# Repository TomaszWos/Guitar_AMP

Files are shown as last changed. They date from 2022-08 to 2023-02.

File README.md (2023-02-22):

# Guitar_AMP
Projekt wzmacniacza lampowego do domowego użytku. 
Podczas projektowania korzystałem ze schematów kultowych konstrukcji takich firm jak Marshall, Fender czy Engl.
Schematy dostępne na https://el34world.com/.

**VER_1** 

Pierwsza wersja wzmacniacza została oparta na schemacie AX84. 

Różnice występują jedynie w wartościach poszczególnych elementów.

Jest to jednokanałowy, lampowy wzmacniacz gitarowy. Układ przedwzmacniacza oparty jest na lampie ECC83 i inspirowany jest konstrukcjami Fendera.
Pozwala uzyskać klasyczne brzmienia od czystych do lekkiego chrunchu. Układ wzmacniacza mocy zbudowany został na EL84 w klasie A. Ponad to wzmacniacz posiada EQ, którego kostrukcja jest klasycznym trzystopniowe EQ jakie występowało w pierwszych wzmacniacza Fendera, Marshalla lub Voxa. 
Od nowa zostały policzone wartości napięć w układzie zasilającym oraz napięcia biasu poszczególnych katod lamp.
Układ jest podstawą do dalszych zmian i modyfikacji.

**VER_1.1**

Pierwsze modyfikacje zostały wprowadzone do układu przedwzmacniacza, tak aby rozszerzyć możliwości brzmieniowe wzmacniacza.
Została dodana druga lampa ECC83 w celu uzystania większego wzmocnienia i większej możliwości kształtowania brzmienia. Zmiana potencjometru GAIN na 1M zwiększyła wzmocnienie pierwszej triody, a co za tym idzie uzyskanie większego przesterowania.
Dodano drugi potencjometr GAIN za drugą triodą. Rozszerzono układ o drugi kanał o dużym przesterowaniu. Przełącznik SW1 służy do zmiany kanałów. Przester tworzy układ diod, które zaczynają przewodzić po osiągnięciu około napięcia 2V. Sygnał zostaje ścięty i kształtem jest zbliżony do prostokątnego. Kondensator 1n przepuszcza wysokie częstotliwości tak, aby dźwięk był mniej syczący. 
Rezystor na pierwszej katodzie zmieniono na 2.2k a kondensator na 680n. Sprawia to, że wyższe częstotliwości są bardziej wzmacniane niż niskie. Dodano kondensatory na torze sygnałowym tak, aby zwiększyć zawartość wyższych harmonicznych w sygnale. Brzmienie jest znacznie jaśniejsze i bardziej szkliste na wzór wzmacniaczy Marshall.

**VER_2**

W pełni lampowy wzmacniacz w klasie A z dwoma kanałami : Clean i Lead. Kanał Lead jest oparty na 4 triodach i jest stylizowany na wzmacniaczach typu Hi-Gain firmy ENGL.

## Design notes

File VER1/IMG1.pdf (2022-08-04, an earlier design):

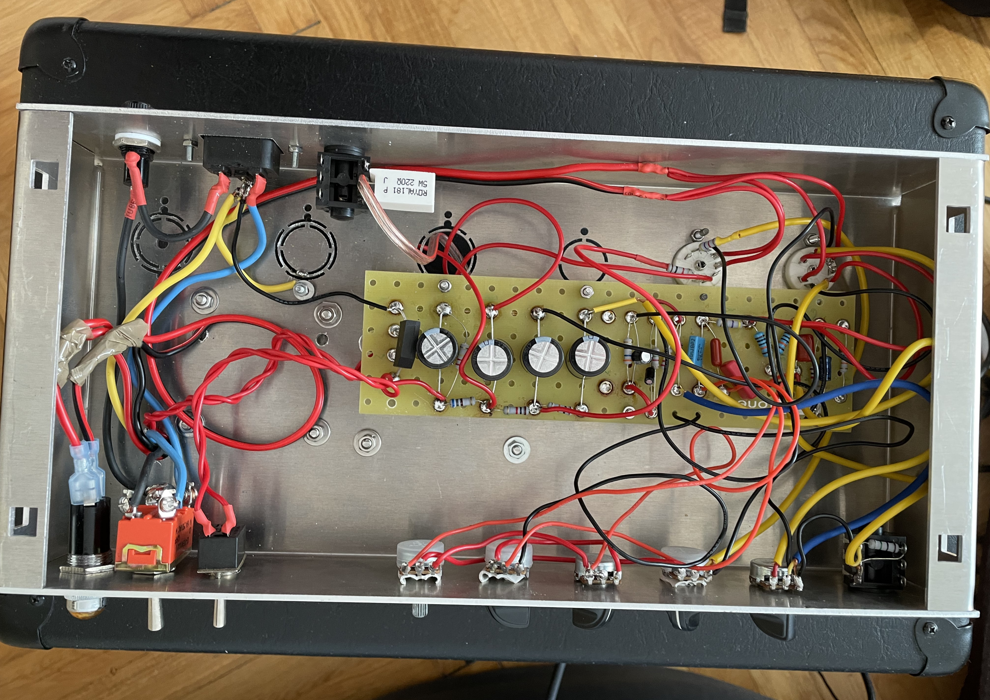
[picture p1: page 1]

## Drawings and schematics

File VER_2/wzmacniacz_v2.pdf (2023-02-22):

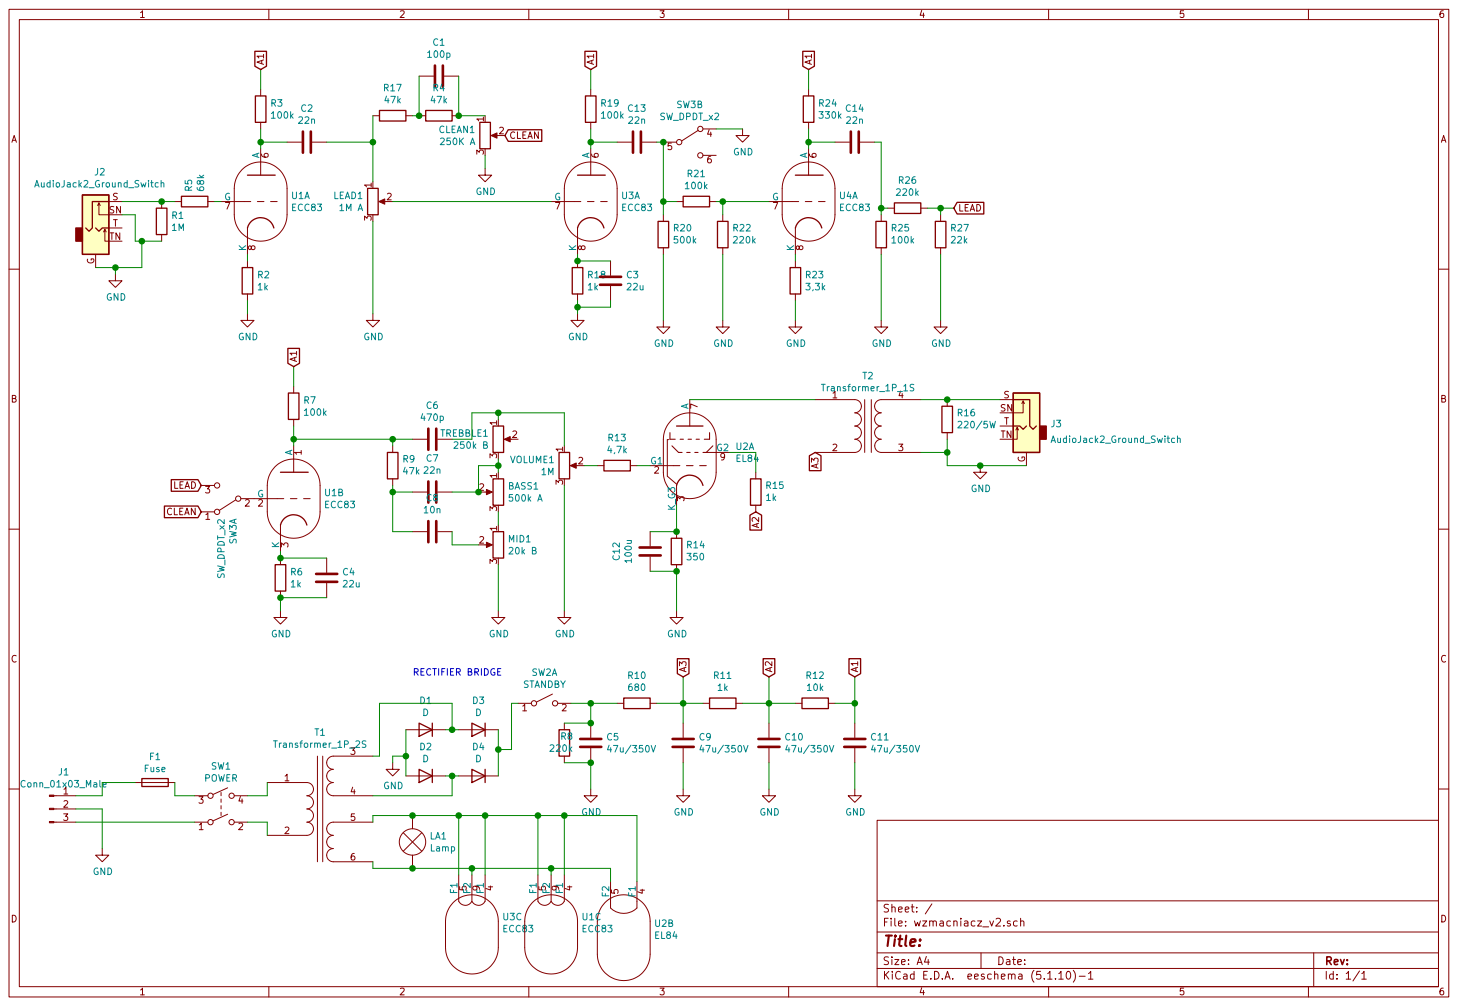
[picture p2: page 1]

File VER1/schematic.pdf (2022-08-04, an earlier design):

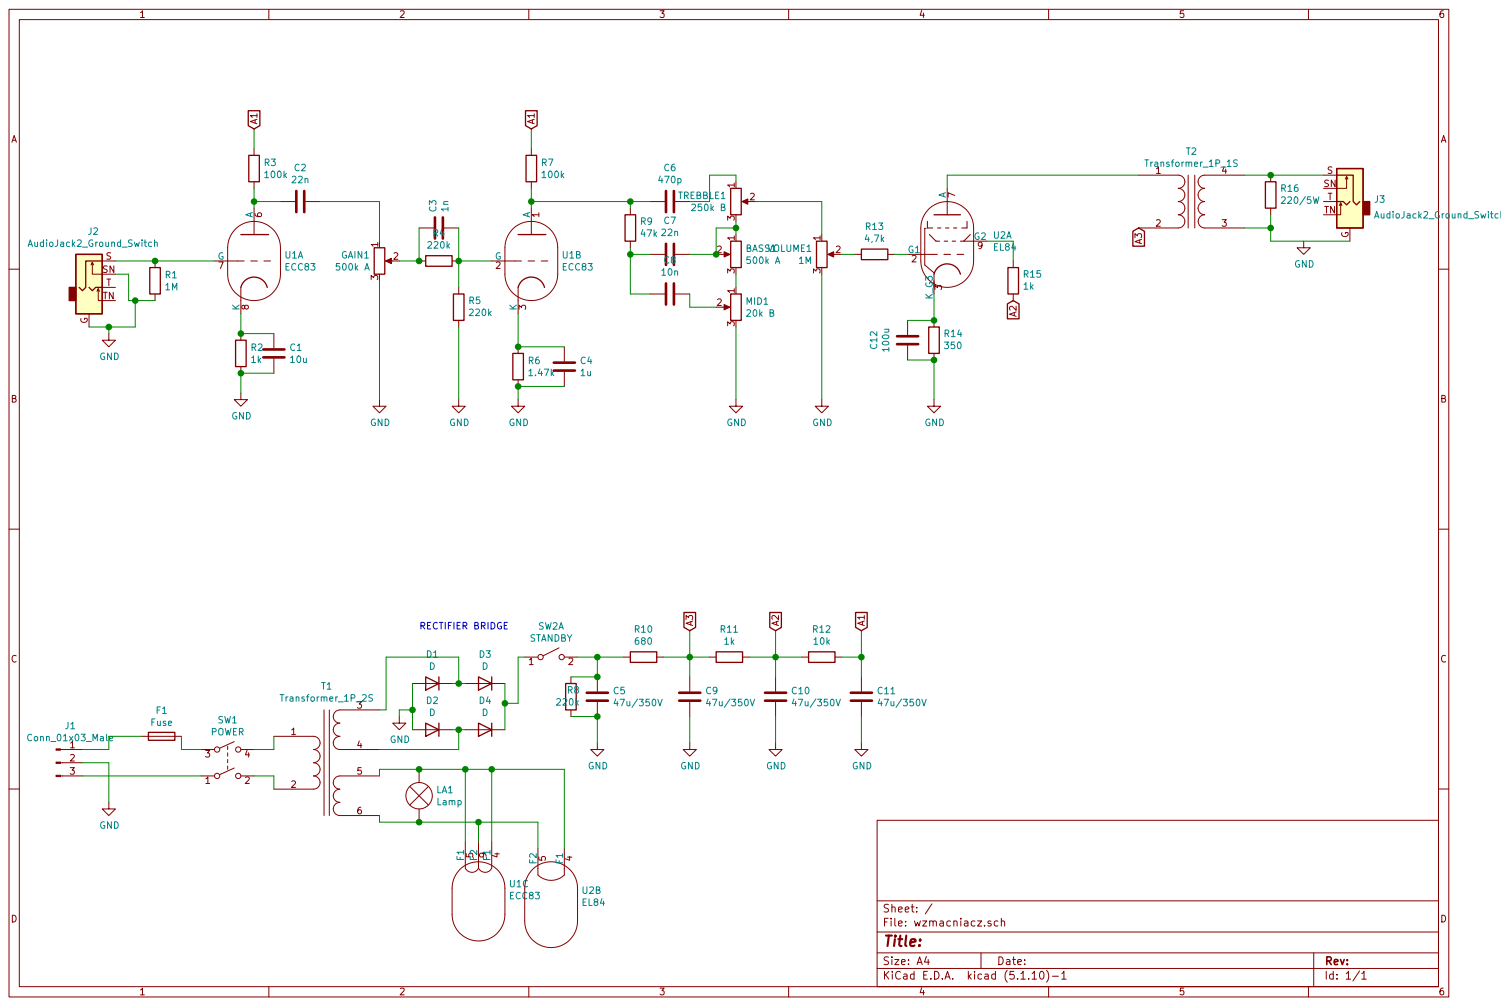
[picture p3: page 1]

Id: 1/1 Title: File: wzmacniacz.sch Sheet: / GND

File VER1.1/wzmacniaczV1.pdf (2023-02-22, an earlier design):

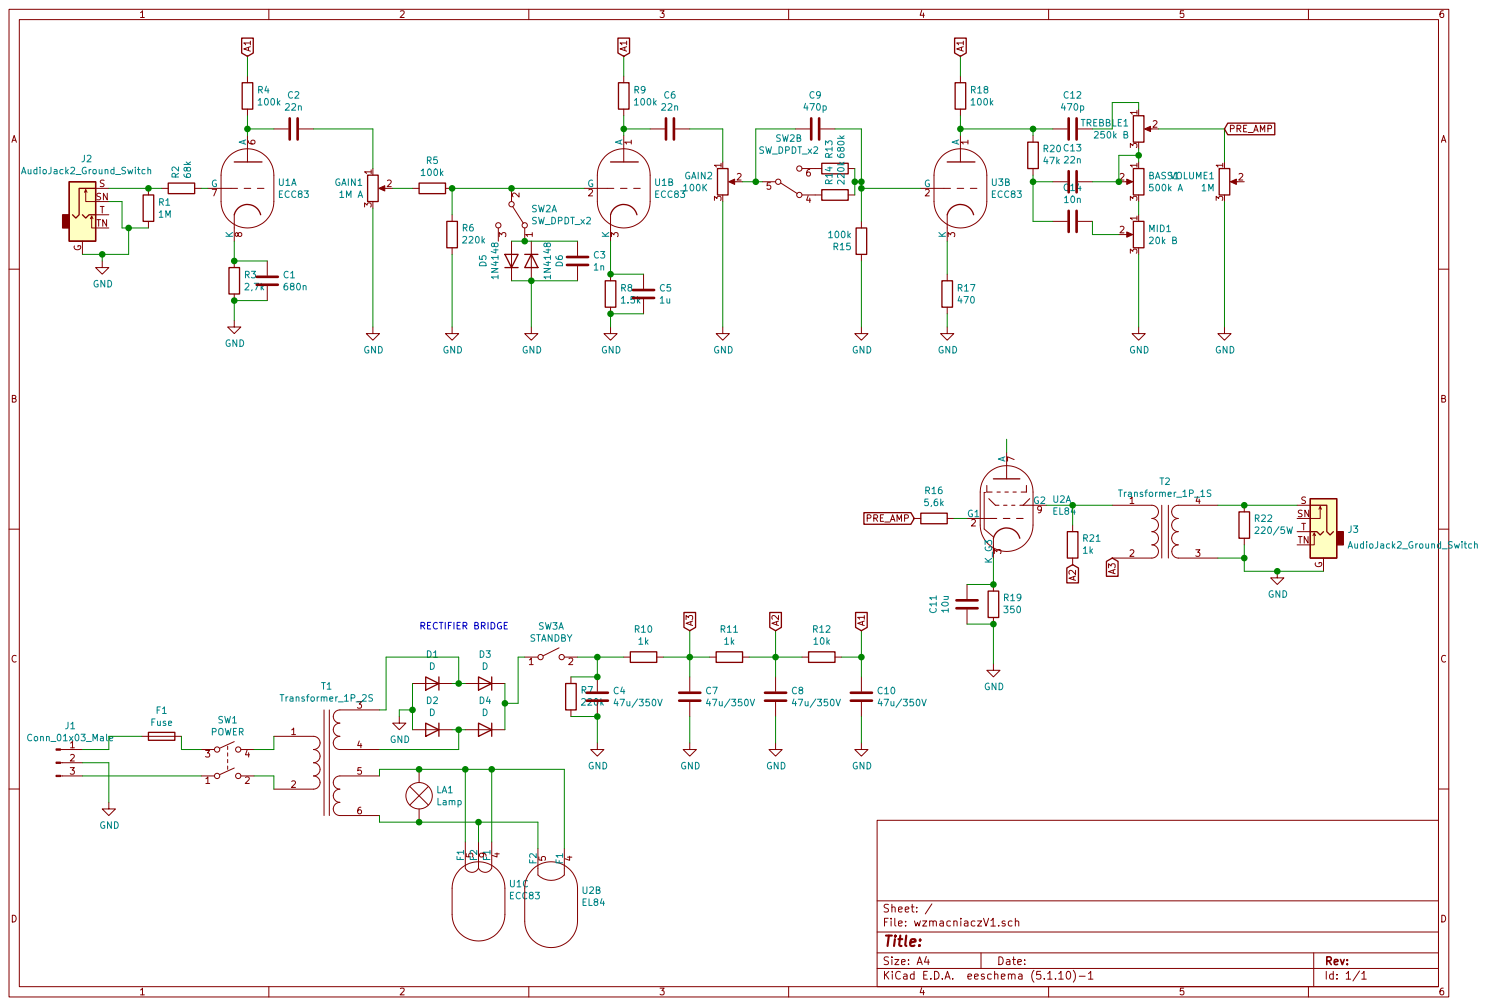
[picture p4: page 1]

Id: 1/1 Title: File: wzmacniaczV1.sch Sheet: / D4D

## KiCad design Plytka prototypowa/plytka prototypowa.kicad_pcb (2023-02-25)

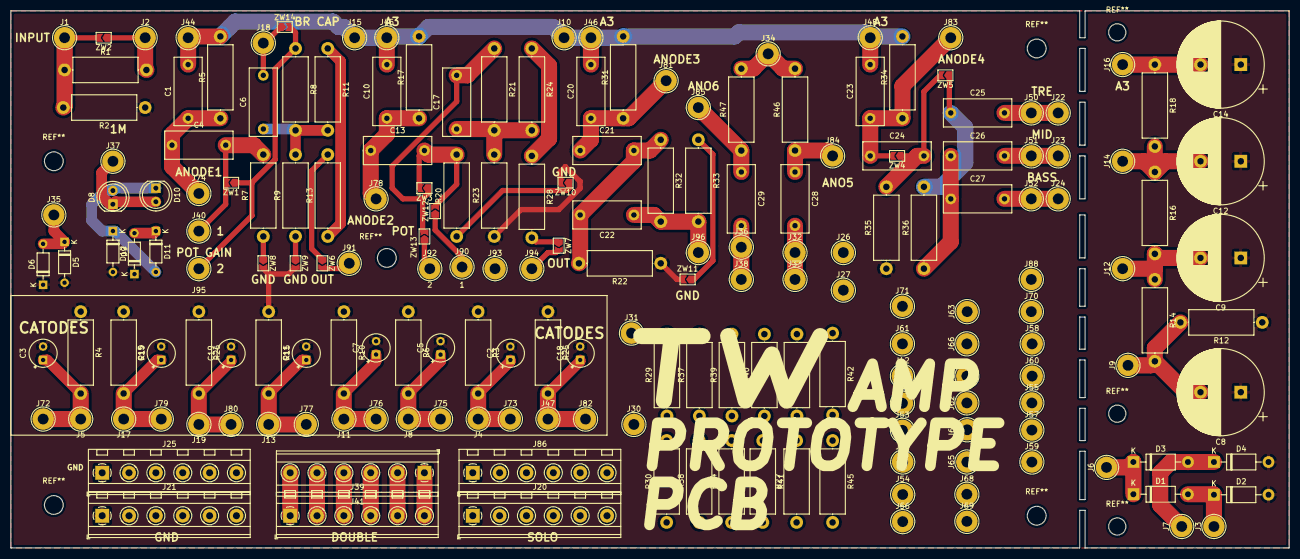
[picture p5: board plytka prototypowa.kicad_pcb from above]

Board: 2 copper layers, 238.0 x 100.0 mm, 192 parts (0 on the bottom side), 65 nets.

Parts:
C1, C4, C6, C10, C13, C17, C20, C21, C22, C23, C24, C25, C26, C27, C28, C29: C; C_Disc_D12.5mm_W5.0mm_P10.00mm
C2, C3, C5, C7, C11, C15, C18, C19: C; CP_Radial_Tantal_D5.0mm_P2.50mm
C8, C9, C12, C14: C; CP_Radial_D16.0mm_P7.50mm
D1, D2, D3, D4: 1N4007; D_DO-41_SOD81_P10.16mm_Horizontal
D5, D6, D9, D11, D12: 1N4148; D_DO-35_SOD27_P7.62mm_Horizontal
D8, D10: LED; LED_D5.0mm
J1: INPUT; TestPoint_THTPad_D4.0mm_Drill2.0mm
J2: INPUT2; TestPoint_THTPad_D4.0mm_Drill2.0mm
J3, J7: AC; TestPoint_THTPad_D4.0mm_Drill2.0mm
J4, J5, J6, J8, J11, J13, J17, J18, J19, J26, J27, J30, J31, J32, J33, J34, J35, J36, J37, J38, J40, J42, J43, J44, J45, J46, J47, J48, J49, J50, J51, J52, J53, J54, J55, J56, J57, J58, J59, J60, J61, J62, J63, J64, J65, J66, J67, J68, J69, J70, J71, J72, J73, J74, J75, J76, J77, J78, J79, J80, J81, J82, J83, J84, J85, J88, J90, J91, J92, J93, J94, J95, J96: Conn_01x01_Male; TestPoint_THTPad_D4.0mm_Drill2.0mm
J9: IN POWER; TestPoint_THTPad_D4.0mm_Drill2.0mm
J10, J15, J16: A3; TestPoint_THTPad_D4.0mm_Drill2.0mm
J12: A1; TestPoint_THTPad_D4.0mm_Drill2.0mm
J14: A2; TestPoint_THTPad_D4.0mm_Drill2.0mm
J20, J86: LUŹNE; TerminalBlock_MetzConnect_Type094_RT03506HBLU_1x06_P5.00mm_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
J21: MASA; TerminalBlock_MetzConnect_Type094_RT03506HBLU_1x06_P5.00mm_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
J22: Treble; TestPoint_THTPad_D4.0mm_Drill2.0mm
J23: MID; TestPoint_THTPad_D4.0mm_Drill2.0mm
J24: Bass; TestPoint_THTPad_D4.0mm_Drill2.0mm
J25: MASA2; TerminalBlock_MetzConnect_Type094_RT03506HBLU_1x06_P5.00mm_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
J39: Conn_01x06_Male; TerminalBlock_MetzConnect_Type094_RT03506HBLU_1x06_P5.00mm_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
J41: LUŹNE2; TerminalBlock_MetzConnect_Type094_RT03506HBLU_1x06_P5.00mm_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
R1, R3, R4, R5, R6, R7, R8, R9, R10, R11, R12, R13, R14, R15, R16, R17, R18, R19, R20, R21, R22, R23, R24, R25, R26, R27, R28, R29, R30, R31, R32, R33, R34, R35, R36, R37, R38, R39, R40, R41, R42, R43, R44, R45, R46, R47: R; R_Axial_DIN0414_L11.9mm_D4.5mm_P15.24mm_Horizontal
R2: 1M; R_Axial_DIN0414_L11.9mm_D4.5mm_P15.24mm_Horizontal
ZW1, ZW2, ZW3, ZW4, ZW5, ZW6, ZW7, ZW8, ZW9, ZW10, ZW11, ZW12, ZW13, ZW14: R; SolderJumper-2_P1.3mm_Open_TrianglePad1.0x1.5mm

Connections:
GND: C2.2, C3.2, C5.2, C7.2, C8.1, C9.1, C11.2, C12.1, C14.1, C15.2, C18.2, C19.2, D2.2, D4.2, D5.2, D6.1, D9.2, D12.1, J21.1, J21.2, J21.3, J21.4, J21.5, J21.6, J25.1, J25.2, J25.3, J25.4, J25.5, J25.6, R2.1, R3.1, R4.1, R6.1, R10.1, R12.1, R15.1, R19.1, R22.1, R23.1, R25.1, R26.1, R35.1, ZW8.2, ZW9.2, ZW10.2, ZW11.2
unnamed: C1.1, C4.1, J74.1, R5.1
unnamed: C1.2, C10.2, C20.2, C23.2, J10.1, J15.1, J44.1, J45.1, J46.1, J48.1, R5.2, R17.2, R31.2, R34.2
unnamed: C2.1, J4.1, J73.1, R3.2
unnamed: C3.1, J5.1, J72.1, R4.2
unnamed: C4.2, J40.1, R7.2, ZW1.2
unnamed: C5.1, J8.1, J75.1, R6.2
unnamed: C6.1, R8.2, R9.2, R11.2
unnamed: C6.2, J18.1, ZW14.1
unnamed: C7.1, J11.1, J76.1, R10.2
unnamed: C8.2, J9.1, R12.2, R14.2
unnamed: C9.2, J12.1, R14.1, R16.2
unnamed: C10.1, C13.1, J78.1, R17.1
unnamed: C11.1, J13.1, J77.1, R15.2
unnamed: C12.2, J14.1, R16.1, R18.2
unnamed: C13.2, R20.2, ZW3.2, ZW12.2
unnamed: C14.2, J16.1, R18.1
unnamed: C15.1, J17.1, J79.1, R19.2
unnamed: C17.1, R21.2, R23.2, R24.2
unnamed: C17.2, R21.1, ZW3.1, ZW13.2
unnamed: C18.1, J47.1, J82.1, R25.2
unnamed: C19.1, J19.1, J80.1, R26.2
unnamed: C20.1, C21.1, J81.1, R31.1
unnamed: C21.2, C22.2, R22.2, R32.1
unnamed: C22.1, J96.1, R32.2, R33.2
unnamed: C23.1, C24.1, J83.1, R34.1, ZW4.2
unnamed: C24.2, R35.2, ZW4.1, ZW5.2
unnamed: C25.1, R36.2, ZW5.1
unnamed: C25.2, J22.1, J50.1
unnamed: C26.1, C27.1, R36.1
unnamed: C26.2, J23.1, J51.1
unnamed: C27.2, J24.1, J52.1
unnamed: C28.1, J84.1, R46.1
unnamed: C28.2, J32.1, J33.1
unnamed: C29.1, J85.1, R47.1
unnamed: C29.2, J36.1, J38.1
unnamed: D1.1, D3.1, J6.1
unnamed: D1.2, D2.1, J3.1
unnamed: D3.2, D4.1, J7.1
unnamed: D5.1, D6.2, J35.1
unnamed: D8.2, D9.1, D10.1, D11.2
unnamed: D8.1, D10.2, J37.1
unnamed: D11.1, D12.2
unnamed: J1.1, R1.1, R2.2, ZW2.2
unnamed: J2.1, R1.2, ZW2.1
unnamed: J34.1, R46.2, R47.2
unnamed: J39.1, J41.6
unnamed: J39.2, J41.5
unnamed: J39.3, J41.4
unnamed: J39.4, J41.3
unnamed: J39.5, J41.2
unnamed: J39.6, J41.1
unnamed: J90.1, ZW12.1
unnamed: J91.1, ZW6.2
unnamed: J92.1, ZW13.1
unnamed: J94.1, ZW7.2
unnamed: J95.1, R8.1, ZW1.1, ZW14.2
unnamed: R7.1, ZW8.1
unnamed: R9.1, ZW9.1
unnamed: R11.1, R13.1
unnamed: R13.2, ZW6.1
unnamed: R20.1, ZW10.1
unnamed: R24.1, R28.1
unnamed: R28.2, ZW7.1
unnamed: R33.1, ZW11.1
